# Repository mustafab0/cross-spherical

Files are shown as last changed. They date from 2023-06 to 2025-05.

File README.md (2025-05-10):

# Cross Spherical gear actuation

#### Original work here:
<p align="center">
  <a href="https://www.youtube.com/watch?v=hhDdfiRCQS4">
    ABENICS: Active Ball Joint Mechanism With Three-DoF Based on Spherical Gear Meshings<br>
    Watch the original work on youtube.
  </a>
</p>

# My implementation 
This project involves the use of 3D printing to create various components. The project's centerpiece is the cross-spherical gear, driven by two actuators, each equipped with two motors. While the original design utilized Brushless DC motors from Maxon Motor Inc, this project opts for NEMA17 stepper motors to reduce cost and complexity. The stepper motors are controlled using TMC2208 stepper motor drivers, which are interfaced with Teensy4.0.

<p align="center">
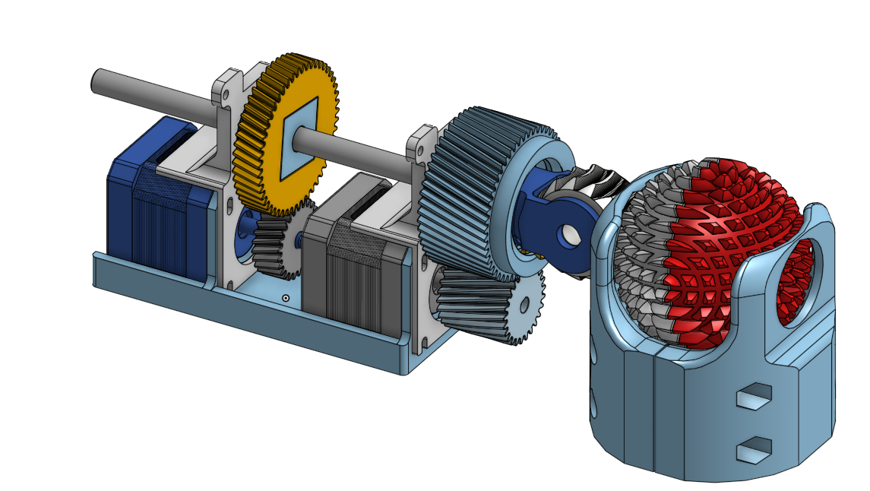
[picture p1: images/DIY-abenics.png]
ABENICS, The original implementation
  <br>
</p>

The gear system is driven by actuators, each equipped with two NEMA17 stepper motors. These motors provide the necessary torque and precision for the gear mechanism. The TMC2208 stepper motor drivers, controlled by an overclocked Teensy4.0 microcontroller, ensure smooth and accurate motor operation. The Teensy4.0 is overclocked to 916 MHz to handle all four motors, inverse kinematics, UI, and sensor feedback.

All components are 3D printed on FDM printers.

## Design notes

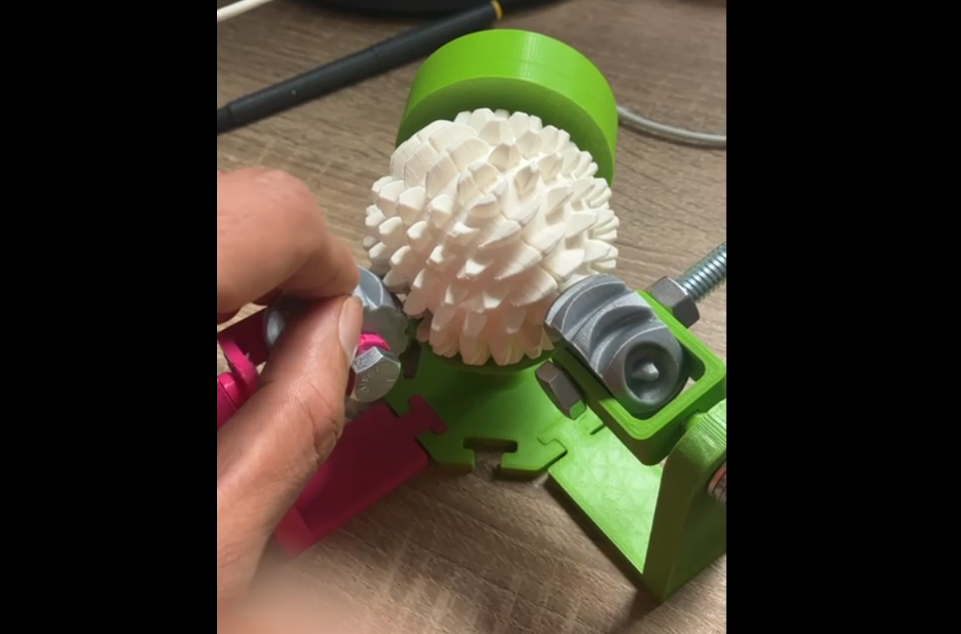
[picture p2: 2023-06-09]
docs/images/ver2_img4.png

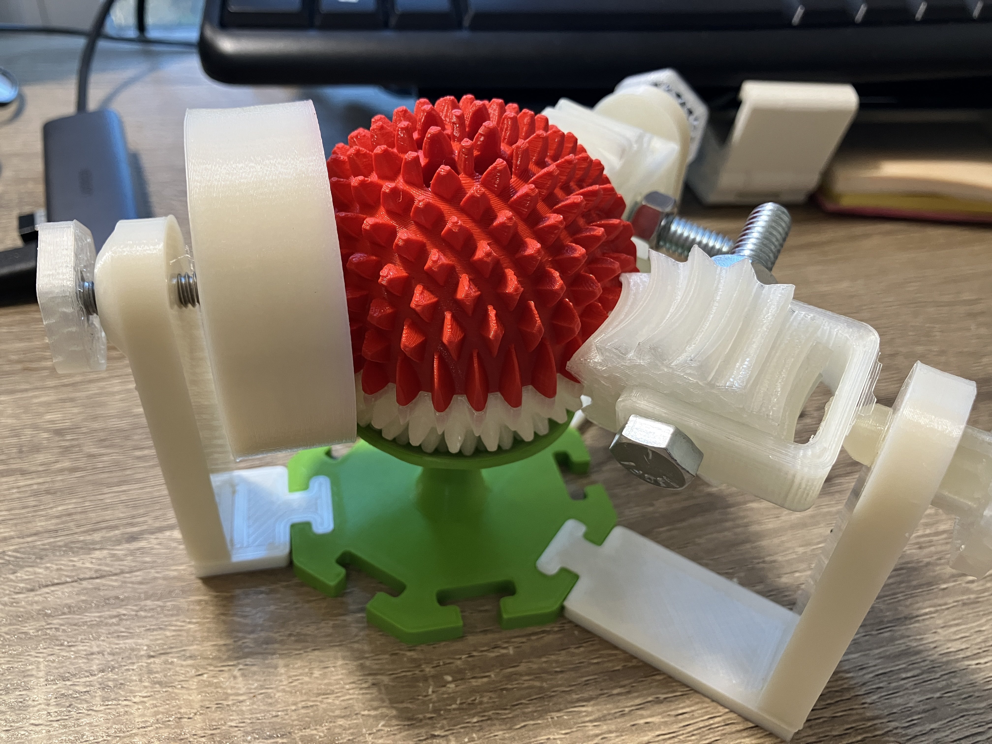
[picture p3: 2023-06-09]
docs/images/ver2_img1.jpg

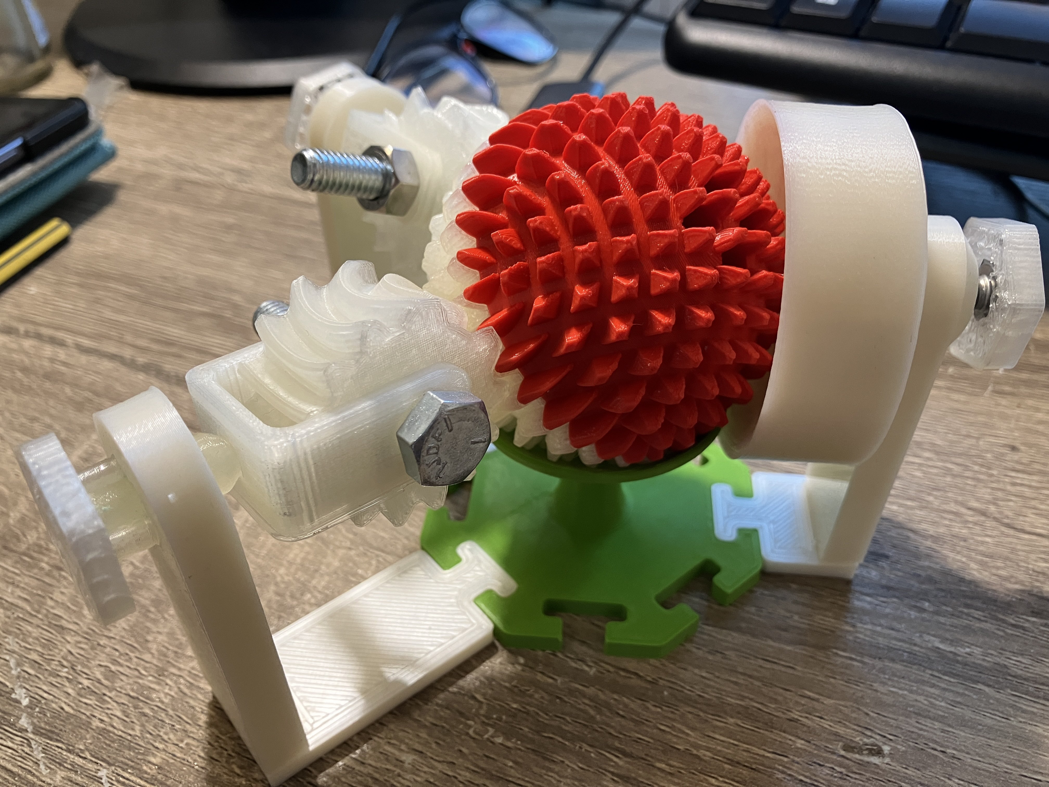
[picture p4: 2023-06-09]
docs/images/ver2_img3.jpg

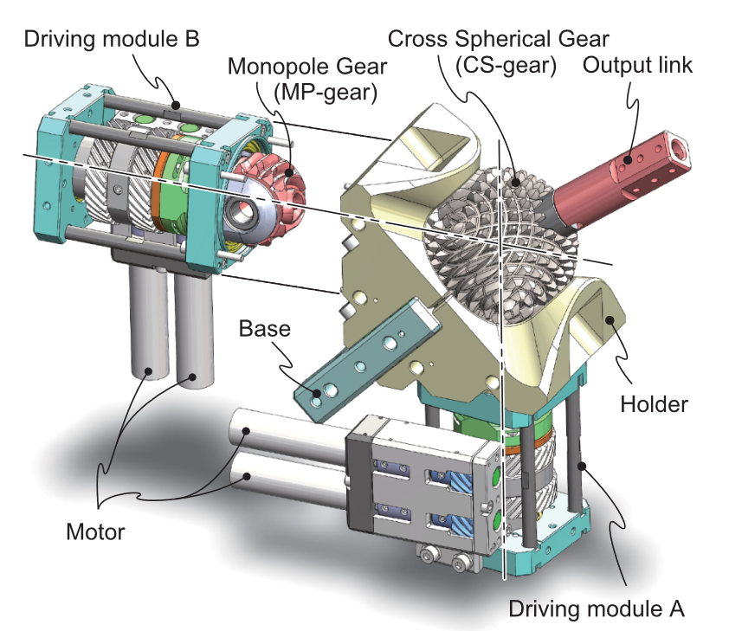
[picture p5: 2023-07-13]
docs/images/ABENICS.png

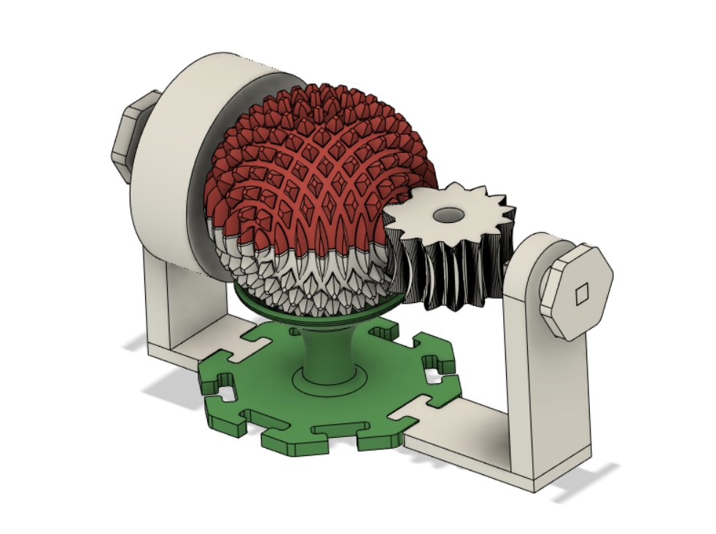
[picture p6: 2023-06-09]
docs/images/ver2_img2.png

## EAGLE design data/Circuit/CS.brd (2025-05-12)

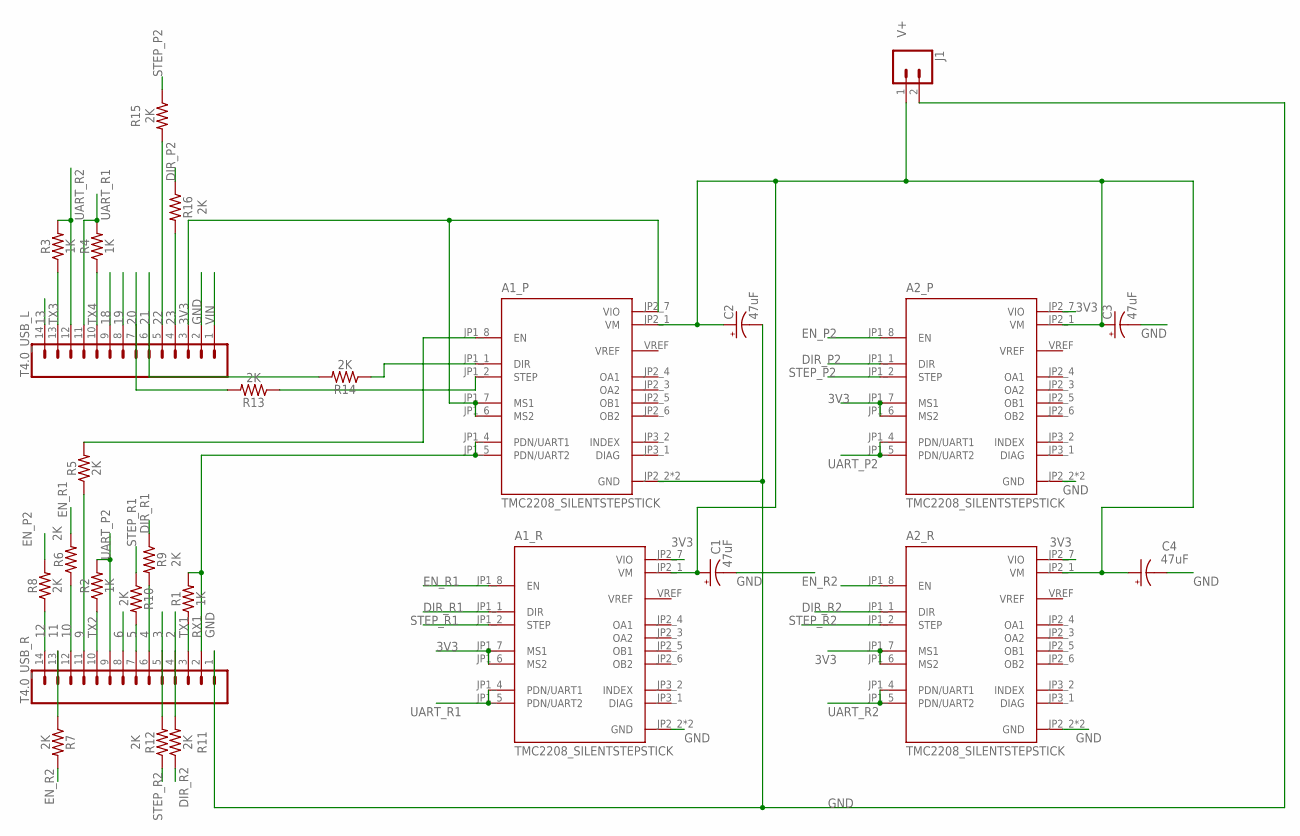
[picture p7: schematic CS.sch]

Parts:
A1_P, A1_R, A2_P, A2_R: TMC2208_SILENTSTEPSTICK; MODULE_TMC2208_SILENTSTEPSTICK
C1, C2, C3, C4: 47uF; CPOL-RADIAL-2.5MM-6.5MM
J1: CONN_02; 1X02
R1, R2, R3, R4: 1K; AXIAL-0.3
R5, R6, R7, R8, R9, R10, R11, R12, R13, R14, R15, R16: 2K; AXIAL-0.3
T4.0_USB_L, T4.0_USB_R: CONN_14; 1X14

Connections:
2: R11.P$2 (2), T4.0_USB_R.4
3: R12.P$2 (2), T4.0_USB_R.5
3V3: A1_P.JP1_6 (MS2), A1_P.JP1_7 (MS1), A1_P.JP2_7 (VIO), A1_R.JP1_6 (MS2), A1_R.JP1_7 (MS1), A1_R.JP2_7 (VIO), A2_P.JP1_6 (MS2), A2_P.JP1_7 (MS1), A2_P.JP2_7 (VIO), A2_R.JP1_6 (MS2), A2_R.JP1_7 (MS1), A2_R.JP2_7 (VIO), T4.0_USB_L.3
4: R9.P$2 (2), T4.0_USB_R.6
5: R10.P$2 (2), T4.0_USB_R.7
6: T4.0_USB_R.8
9: R5.P$1 (1), T4.0_USB_R.11
10: R6.P$1 (1), T4.0_USB_R.12
11: R7.P$1 (1), T4.0_USB_R.13
12: R8.P$1 (1), T4.0_USB_R.14
13: T4.0_USB_L.14
18: T4.0_USB_L.9
19: T4.0_USB_L.8
20: R13.P$2 (2), T4.0_USB_L.7
21: R14.P$2 (2), T4.0_USB_L.6
22: R15.P$2 (2), T4.0_USB_L.5
23: R16.P$2 (2), T4.0_USB_L.4
DIR_P2: A2_P.JP1_1 (DIR), R16.P$1 (1)
DIR_R1: A1_R.JP1_1 (DIR), R9.P$1 (1)
DIR_R2: A2_R.JP1_1 (DIR), R11.P$1 (1)
EN_P2: A2_P.JP1_8 (EN), R8.P$2 (2)
EN_R1: A1_R.JP1_8 (EN), R6.P$2 (2)
EN_R2: A2_R.JP1_8 (EN), R7.P$2 (2)
GND: A1_P.JP2_2 (GND), A1_P.JP2_8 (GND), A1_R.JP2_2 (GND), A1_R.JP2_8 (GND), A2_P.JP2_2 (GND), A2_P.JP2_8 (GND), A2_R.JP2_2 (GND), A2_R.JP2_8 (GND), C1.2 (-), C2.2 (-), C3.2 (-), C4.2 (-), J1.2, T4.0_USB_L.2, T4.0_USB_R.1
unnamed: A1_P.JP1_8 (EN), R5.P$2 (2)
unnamed: A1_P.JP2_1 (VM), C2.1 (+)
unnamed: A1_P.JP1_2 (STEP), R13.P$1 (1)
unnamed: A1_P.JP1_1 (DIR), R14.P$1 (1)
RX1: A1_P.JP1_4 (PDN/UART1), A1_P.JP1_5 (PDN/UART2), R1.P$2 (2), T4.0_USB_R.2
STEP_P2: A2_P.JP1_2 (STEP), R15.P$1 (1)
STEP_R1: A1_R.JP1_2 (STEP), R10.P$1 (1)
STEP_R2: A2_R.JP1_2 (STEP), R12.P$1 (1)
TX1: R1.P$1 (1), T4.0_USB_R.3
TX2: R2.P$1 (1), T4.0_USB_R.10
TX3: R3.P$1 (1), T4.0_USB_L.13
TX4: R4.P$1 (1), T4.0_USB_L.10
UART_P2: A2_P.JP1_4 (PDN/UART1), A2_P.JP1_5 (PDN/UART2), R2.P$2 (2), T4.0_USB_R.9
UART_R1: A1_R.JP1_4 (PDN/UART1), A1_R.JP1_5 (PDN/UART2), R4.P$2 (2), T4.0_USB_L.11
UART_R2: A2_R.JP1_4 (PDN/UART1), A2_R.JP1_5 (PDN/UART2), R3.P$2 (2), T4.0_USB_L.12
V+: A1_R.JP2_1 (VM), A2_P.JP2_1 (VM), A2_R.JP2_1 (VM), C1.1 (+), C3.1 (+), C4.1 (+), J1.1
VIN: T4.0_USB_L.1

Board: 2 copper layers, 27 parts (0 on the bottom side), 36 nets, no tracks yet.

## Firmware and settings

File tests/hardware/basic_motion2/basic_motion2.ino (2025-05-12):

// Author Teemu Mäntykallio, 2017-04-07

// Include the necessary libraries for each motor
#include <TMC2208Stepper.h>
#include <math.h>

#define CW 1
#define CCW 0

// Define pins for each motor
#define   EN_PIN_P1 9
#define STEP_PIN_P1 20
#define  DIR_PIN_P1 21

#define   EN_PIN_R1 10
#define STEP_PIN_R1 5
#define  DIR_PIN_R1 4

#define   EN_PIN_R2 11
#define STEP_PIN_R2 3
#define  DIR_PIN_R2 2

#define   EN_PIN_P2 12
#define STEP_PIN_P2 22
#define  DIR_PIN_P2 23

// a class for a stepper motor driver that only uses the enable, step, and direction pins
class StepperDriver {
   public:
    StepperDriver(int en_pin, int step_pin, int dir_pin)
      : en_pin(en_pin), step_pin(step_pin), dir_pin(dir_pin), dir(0) {
      pinMode(en_pin, OUTPUT);
      pinMode(step_pin, OUTPUT);
      pinMode(dir_pin, OUTPUT);
      this->enable();
      this->setSpeed(70);
      Serial.println("StepperDriver created");
    }

    void setDirection(int dir) {
      this->dir = dir;
      digitalWrite(dir_pin, this->dir);
    }
    void setSpeed(float speed){
        //speed is input as percentage of max speed
        this->speed = 1000 - speed*9.7;
    }
    void enable(){
        digitalWrite(en_pin, LOW);
    }
    void disable(){
        digitalWrite(en_pin, HIGH);
    }

    void step() {
      digitalWrite(step_pin, !digitalRead(step_pin));
      delayMicroseconds(speed); 
      this->step_counter();
    }

    void step_counter(){
      if (this->dir == CW){
        steps++;
      }
      else{
        steps--;
      }
    }

    void steps_to_degrees(){
        float angle = (steps/MICRO_STEPS)/REV_STEPS*360;
        //constrain degrees to 0-360
        angle = fmod(angle, 360);
        if (angle<0){
            angle = 360 + angle;
        }
        degrees =  angle;
    }

    int degrees_to_steps(float angle){
        return (angle/360)*REV_STEPS*MICRO_STEPS;
    }

    void move(float angle){
        int steps = degrees_to_steps(angle);
        if (steps<0){
            this->setDirection(CCW);
            for(int i = 0; i < abs(steps); i++){
                this->step();
            }
        }
        else{
            this->setDirection(CW);
            for(int i = 0; i < abs(steps); i++){
                this->step();
            }
        }
        steps_to_degrees();
    }

    void setSteps(int steps){
        this->steps = steps;
    }

    int getSteps(){
        return this->steps;
    }

    float getDegrees(){
        return this->degrees;
    }



  private:
    int en_pin;
    int step_pin;
    int dir_pin;
    int dir;
    int speed;
    int steps=0;
    float degrees=0;
    const float MICRO_STEPS = 16.;
    const float REV_STEPS = 400.;
};

class Actuator {
  public:
    Actuator(int roll_en, int roll_step, int roll_dir, int pitch_en, int pitch_step, int pitch_dir)
      : roll(roll_en, roll_step, roll_dir), pitch(pitch_en, pitch_step, pitch_dir) {
      pitch.setSpeed(90);
      Serial.println("Actuator created with Roll and Pitch Stepper Drivers");
    }

    void moveRoll(float angle) {
      Serial.print("Moving roll to angle: ");
      Serial.println(angle);

      angle = angle*2;  //Gear ratio of 2:1
      roll.move(angle);
    }

    void movePitch(float angle) {
      Serial.print("Moving pitch to angle: ");
      Serial.println(angle);

      angle =angle*32;  //Gear ratio of 32:1
      pitch.move(angle);
    }

    float getRollAngle() {
      roll_angle = steps_to_degrees(roll.getSteps()/2.);
      return roll_angle;
    }

    float getPitchAngle() {
      pitch_angle = steps_to_degrees(pitch.getSteps()/32.);
      return pitch_angle;
    }

    void setRollSpeed(float speed) {
      Serial.print("Setting roll speed to: ");
      Serial.println(speed);
      roll.setSpeed(speed);
    }

    void setPitchSpeed(float speed) {
      Serial.print("Setting pitch speed to: ");
      Serial.println(speed);
      pitch.setSpeed(speed);
    }

    float steps_to_degrees(int steps){
        float angle = (steps/16.)/400.0*360;
        //constrain degrees to 0-360
        angle = fmod(angle, 360);
        if (angle<0){
            angle = 360 + angle;
        }
        return angle;

    }

    void homeRoll() {
      Serial.println("Homing roll");
      int adj = 1;
      while(adj!=0){
        Serial.println("Enter degrees to adjust: (Press 0 to finish)");
        while(Serial.available() == 0);
        adj = Serial.parseInt();
        moveRoll(adj);
      }
      roll.setSteps(0);
    }

    void homePitch() {
      Serial.println("Homing pitch");
      int adj = 1;
      while(adj!=0){
        Serial.println("Enter degrees to adjust: (Press 0 to finish)");
        while(Serial.available() == 0);
        adj = Serial.parseInt();
        movePitch(adj);
      }
      pitch.setSteps(0);
    }

    void enable() {
      roll.enable();
      pitch.enable();
    }

    void disable() {
      roll.disable();
      pitch.disable();
    }

  
    StepperDriver roll;
    StepperDriver pitch;
    float roll_angle = 0;
    float pitch_angle = 0;
};

class MotionController {
  public:
    MotionController(Actuator a1, Actuator a2)
      : a1(a1), a2(a2) {
      Serial.println("MotionController created with Actuators a1 and a2");
    }

    void Roll(float angle) {
      angle = angle*2;  //Gear ratio of 2:1
      angle = degrees_to_steps(angle);
      a1.roll.setDirection(angle>0);
      a1.pitch.setDirection(angle>0);
      a2.roll.setDirection(angle<0);
      a2.pitch.setDirection(angle<0);
      for(int i = 0; i < abs(angle); i++){
        a1.roll.step();
        a1.pitch.step();
        a2.roll.step();
        a2.pitch.step();
      }
    }

    void Pitch(float angle) {
      angle = angle*32;  //Gear ratio of 32:1
      angle = degrees_to_steps(angle);
      a1.pitch.setDirection(angle>0);
      a2.pitch.setDirection(angle>0);
      for(int i = 0; i < abs(angle); i++){
        a1.pitch.step();
        a2.pitch.step();
      }
    }

    void setRollSpeed(float speed) {
      a1.setRollSpeed(speed);
      a2.setRollSpeed(speed);
    }

    void setPitchSpeed(float speed) {
      a1.setPitchSpeed(speed);
      a2.setPitchSpeed(speed);
    }

    int degrees_to_steps(float angle){
        return (angle/360)*400*16;
    }

    void home(Actuator a) {
      Serial.print("Press 1 to continue to home actuator roll: ");
      while(Serial.available() == 0);
      if (Serial.parseInt() == 1) {
        a.homeRoll();
      }

      Serial.print("Press 1 to continue to home actuator pitch: ");
      while(Serial.available() == 0);
      if (Serial.parseInt() == 1) {
        a.homePitch();
      }
    }

    void enable() {
      a1.enable();
      a2.enable();
    }

    void disable() {
      a1.disable();
      a2.disable();
    }

    Actuator a1;
    Actuator a2;
};

Actuator a_one(EN_PIN_R1, STEP_PIN_R1, DIR_PIN_R1, EN_PIN_P1, STEP_PIN_P1, DIR_PIN_P1);
Actuator a_two(EN_PIN_R2, STEP_PIN_R2, DIR_PIN_R2, EN_PIN_P2, STEP_PIN_P2, DIR_PIN_P2);

MotionController mc(a_one, a_two);

void setup() {
    Serial.begin(115200); 
    delay(3000);   
}

void loop(){
  int degrees;
  
   Serial.println("WE successfully uploaded");

  Serial.println("Enter Roll(R) Pitch(P) Homing(H) Config(C) or Quit(Q):");
  while(Serial.available() == 0);
  char input = Serial.read();

  if (input == 'R' || input == 'r') {
    Serial.println("Enter degrees to move roll:");
    while(Serial.available() == 0);
    degrees = Serial.parseInt();
    mc.Roll(degrees);
  }

  else if (input == 'P' || input == 'p') {
    Serial.println("Enter degrees to move pitch:");
    while(Serial.available() == 0);
    degrees = Serial.parseInt();
    mc.Pitch(degrees);
  }

  else if (input == 'H' || input == 'h') {
    Serial.println("Homing Actuator 1:");
    mc.home(mc.a1);
    Serial.println("Homing Actuator 2:");
    mc.home(mc.a2);
  }

  else if (input == 'C' || input == 'c') {
    Serial.println("Enter 1 to enable or 0 to disable:");
    while(Serial.available() == 0);
    int enable = Serial.parseInt();
    if (enable == 1) {
      mc.enable();
    }
    else if (enable == 0) {
      mc.disable();
    }
  }

  else if (input == 'Q' || input == 'q') {
    Serial.println("Quitting");
    mc.disable();
    exit(0);
  }

  else {
    Serial.println("Invalid input");
  }
    
}

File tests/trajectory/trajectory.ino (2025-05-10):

#include <ArduinoEigen.h>
#include <ArduinoEigenDense.h>
#include <ArduinoEigenSparse.h>

#define DEG2RAD 0.0174532925
#define RAD2DEG 57.2957795

Eigen::Matrix3d euler2rotm(const Eigen::Vector3d& euler_angs) {
    double roll = euler_angs(0) * DEG2RAD;
    double pitch = euler_angs(1) * DEG2RAD;
    double yaw = euler_angs(2) * DEG2RAD;
    Eigen::Matrix3d R_x;
    R_x << 1, 0, 0,
           0, cos(roll), -sin(roll),
           0, sin(roll), cos(roll);

    Eigen::Matrix3d R_y;
    R_y << cos(pitch), 0, sin(pitch),
           0, 1, 0,
           -sin(pitch), 0, cos(pitch);

    Eigen::Matrix3d R_z;
    R_z << cos(yaw), -sin(yaw), 0,
           sin(yaw), cos(yaw), 0,
           0, 0, 1;

    Eigen::Matrix3d R = R_z * R_y * R_x;

    return R;
}

struct Quaternion {
    double x;
    double y;
    double z;
    double w;
};

struct Quaternion to_quaternion(const Eigen::Vector3d& rpy) {

    double roll  = rpy(0) * DEG2RAD;
    double pitch = rpy(1) * DEG2RAD;
    double yaw   = rpy(2) * DEG2RAD;

    double cr = std::cos(roll * 0.5);
    double sr = std::sin(roll * 0.5);
    double cp = std::cos(pitch * 0.5);
    double sp = std::sin(pitch * 0.5);
    double cy = std::cos(yaw * 0.5);
    double sy = std::sin(yaw * 0.5);

    struct Quaternion q = {
        sr * cp * cy - cr * sp * sy,
        cr * sp * cy + sr * cp * sy,
        cr * cp * sy - sr * sp * cy,
        cr * cp * cy + sr * sp * sy
    };

    return q;
}

Eigen::Vector3d to_euler_angles(const struct Quaternion& q) {
    Eigen::Vector3d angles;

    // roll (x-axis rotation)
    double sinr_cosp = 2 * (q.w * q.x + q.y * q.z);
    double cosr_cosp = 1 - 2 * (q.x * q.x + q.y * q.y);
    angles(0) = std::atan2(sinr_cosp, cosr_cosp);

    // pitch (y-axis rotation)
    double sinp = std::sqrt(1 + 2 * (q.w * q.y - q.x * q.z));
    double cosp = std::sqrt(1 - 2 * (q.w * q.y - q.x * q.z));
    angles(1) = 2 * std::atan2(sinp, cosp) - M_PI / 2;

    // yaw (z-axis rotation)
    double siny_cosp = 2 * (q.w * q.z + q.x * q.y);
    double cosy_cosp = 1 - 2 * (q.y * q.y + q.z * q.z);
    angles(2) = std::atan2(siny_cosp, cosy_cosp);

    // Convert to degrees
    angles(0) = angles(0) * RAD2DEG;
    angles(1) = angles(1) * RAD2DEG;
    angles(2) = angles(2)* RAD2DEG;

    return angles;
}

struct Quaternion q_slerp(const struct Quaternion& qstart, const struct Quaternion& qend, double t)
{
	// Compute the dot product between the two quaternions
	Eigen::Vector4d q0(qstart.x, qstart.y, qstart.z, qstart.w);
	Eigen::Vector4d q1(qend.x, qend.y, qend.z, qend.w);
	
	double dot = q0.transpose() * q1;
	
	const double DOT_THRESHOLD = 0.9995;
	if (dot > DOT_THRESHOLD)
	{
		// Linearly interpolate and normalize if inputs are too close
		Eigen::Vector4d result = q0 + t * (q1 - q0);
		result /= result.norm();
    struct Quaternion q_result= {
        result(0),
        result(1),
        result(2),
        result(3)
    };
		return q_result;
	}
	
	// Clamp the dot product to stay within the domain of acos()
	dot = std::max(-1.0, std::min(1.0, dot));

	// Compute theta_0 and theta
	double theta_0 = std::acos(dot);
	double theta = theta_0 * t;

 	// Compute intermediate quaternion v2
	Eigen::Vector4d v2 = q1 - q0 * dot;
	v2 /= v2.norm();
	
	// Slerp interpolation
	Eigen::Vector4d result = q0 * std::cos(theta) + v2 * std::sin(theta);

  struct Quaternion q_result= {
        result(0),
        result(1),
        result(2),
        result(3)
    };
	
	return q_result;
}

struct Quaternion q_mult(const struct Quaternion& q1, const struct Quaternion& q2)
{
	struct Quaternion q_result;
	q_result.x = q1.w * q2.x + q1.x * q2.w + q1.y * q2.z - q1.z * q2.y;
	q_result.y = q1.w * q2.y + q1.y * q2.w + q1.z * q2.x - q1.x * q2.z;
	q_result.z = q1.w * q2.z + q1.z * q2.w + q1.x * q2.y - q1.y * q2.x;
	q_result.w = q1.w * q2.w - q1.x * q2.x - q1.y * q2.y - q1.z * q2.z;

	//normalize quaternion
	float q_result_norm = sqrt(q_result.x*q_result.x + q_result.y*q_result.y + q_result.z*q_result.z + q_result.w*q_result.w);
	q_result.x = q_result.x / q_result_norm;
	q_result.y = q_result.y / q_result_norm;
	q_result.z = q_result.z / q_result_norm;
	q_result.w = q_result.w / q_result_norm;

	return q_result;
}


void get_euler_angles(int i, Eigen::Vector3d &end_rpy) {

  Serial.println("Enter euler angles (roll, pitch, yaw):");

  switch (i) {
      case 0:
          Serial.print("Roll: ");
          break;
      case 1:
          Serial.print("Pitch: ");
          break;
      case 2:
          Serial.print("Yaw: ");
          break;
      default:
          break;
    }
  //Clear the input buffer
  while (Serial.available()) {
      Serial.read();
  }
  while (!Serial.available());
  end_rpy(i) = Serial.parseFloat();
  Serial.println(end_rpy(i));

}

void print_euler_angles(Eigen::Vector3d eul_ang) {
    Serial.print(eul_ang(0));
    Serial.print(", ");
    Serial.print(eul_ang(1));
    Serial.print(", ");
    Serial.print(eul_ang(2));
  }

void traj_plan(Eigen::Vector3d &start_rpy, Eigen::Vector3d &end_rpy, std::vector<Eigen::Vector3d> &vec_list)
  {
      struct Quaternion start_quat, end_quat;
      start_quat = to_quaternion(start_rpy);
      end_quat = to_quaternion(end_rpy);
      end_quat = q_mult(end_quat, start_quat);
      end_rpy = to_euler_angles(end_quat);

      Serial.print("Start euler angles: ");
      print_euler_angles(start_rpy);
      Serial.print("\n");

      Serial.print("End euler angles: ");
      print_euler_angles(end_rpy);
      Serial.print("\n");

      struct Quaternion interpolated_quat;
      Eigen::Vector3d interpolated_rpy;
      
      int num_points = 10;
      for (int i = 0; i <= num_points; i++)
      {
          double t = i / (double) num_points;
          interpolated_quat = q_slerp(start_quat, end_quat, t);
          interpolated_rpy = to_euler_angles(interpolated_quat);
          // vec_list.push_back(euler2rotm(interpolated_rpy)*p_vec);   //Uncomment to record the pointer for graphing
          vec_list.push_back(interpolated_rpy);                      //Uncomment to record RPY angles for Inverse Kinematics 
          
      }
      start_rpy = end_rpy;
    }

Eigen::Vector3d start_rpy(0, 0, 0);
Eigen::Vector3d p_vec(0,0,1);

void setup() {
  // put your setup code here, to run once:
  Serial.begin(9600);

  delay(500);

  Serial.println("Trajectory planning");
  
}
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

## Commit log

2023-06-09 Create TMC_CS.ino
    Teensy code for running TMC2208 driver
2023-06-28 added eagle files V1 circuit
    [CS.brd, CS.sch]
2023-06-28 reg update
    [Untitled-1.obj]
2023-06-28 cleaned up schematic
2023-07-03 urdf folder
2023-07-04 urdf file created
    [robot.urdf]
2023-07-12 Added code for actuation with UI. Need to add inverse kinematics
2023-07-13 base drawing
    [plate Drawing 1.dxf]
2023-08-19 trajectory planner
    [Untitled-1.obj]
2023-08-20 trajectory arduino code
2023-08-21 refactored trajectory code
    Refactored trajectory planning arduino code
    Everything working good
2023-11-07 4 steppers working simultaneously
    [controller_box.dxf]
2024-01-07 added set home function
    reworked pitch motion and roll motion function
    [basic_motion.ino]
2024-05-20 added new script with code refactoring
    Refactored basic_motion script and made classes for Stepper motors, actuators and motion controller
2025-05-12 re-organized directory structure
    [Battery Holder.step, CS.brd, CS.sch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]

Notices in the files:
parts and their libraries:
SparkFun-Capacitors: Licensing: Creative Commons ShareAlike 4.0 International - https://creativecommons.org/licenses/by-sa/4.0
